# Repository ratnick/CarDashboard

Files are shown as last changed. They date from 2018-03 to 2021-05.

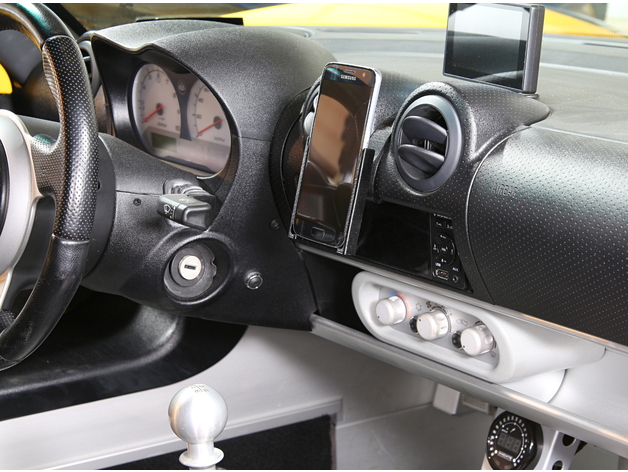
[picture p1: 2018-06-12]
3D print/Phone_mount_for_Lotus_Elise_Exige/images/8231e8743e852b0e2db3741e05d66e65_preview_featured.JPG

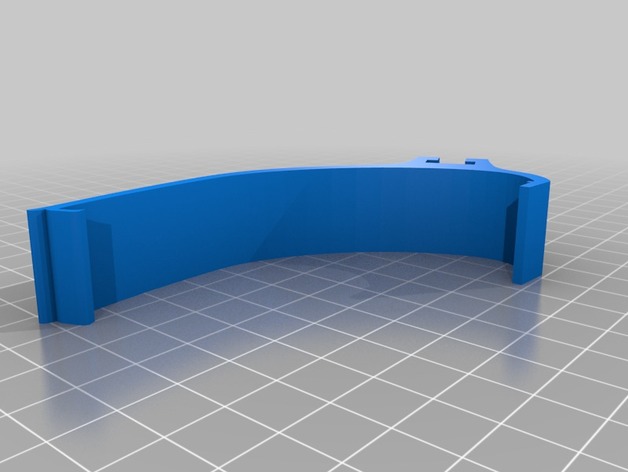
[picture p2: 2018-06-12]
3D print/Phone_mount_for_Lotus_Elise_Exige/images/de6a3d5b6df85b9659bbdc78314f558a_preview_featured.jpg

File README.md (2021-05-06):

# CarDashboard
General use: A dashboard built for car telemetry. 
UI targeted at trackday; i.e. clear no-nonsense visuals.
Content: tyre pressure, tyre temperature, outdoor temperature.
Built scalable to include more metrics.

Content:
Android app with interface to several sensors:
- tire temperature sensors mounted on top of tyre.
      + communicating via wifi/UDP.
      + Arduino based, battery powered, measuring with infrared heat sensor. 
- Tire pressure sensors:
      + communicating via BLE. 
      + VC601 type which seem to work best (https://www.aliexpress.com/item/32902607772.html?spm=a2g0s.9042311.0.0.27424c4dPwDtFs)
      + Chinese No Name which turned out to be unstable. But communication and decoding works (https://www.aliexpress.com/item/33041131063.html?spm=a2g0s.9042311.0.0.27424c4doWNTAi

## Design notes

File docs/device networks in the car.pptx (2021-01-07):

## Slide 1

WeMOS D1
Temp + humidity

NORMAL SETUP

”MX5 ratnick”
Router / AP

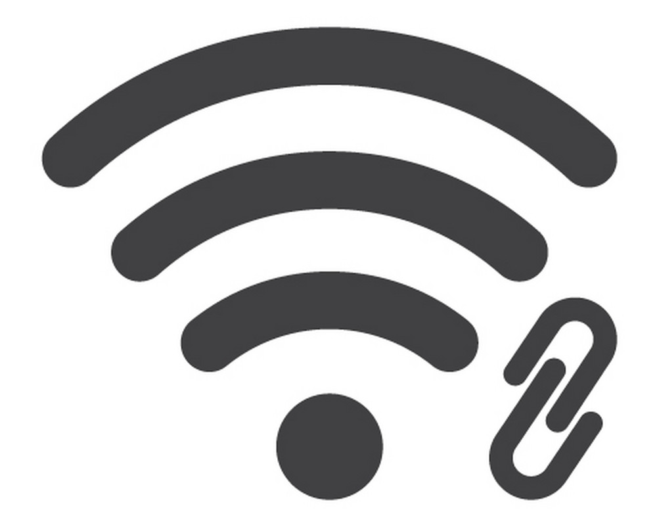
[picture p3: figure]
Wifi hotspot glyph icon web and mobile Royalty Free Vector

Android screen

CAR monitor

WeMOS temperature sensor

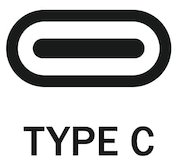
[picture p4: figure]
Usb C Icon Images, Stock Photos & Vectors | Shutterstock

Phone

Headset

Normal drive

12V

12V

TPMS monitor

TPMS sensors

RACE SETUP

”MX5 ratnick”
Router / AP

Android screen

CAR monitor

GoPro CAM

Phone

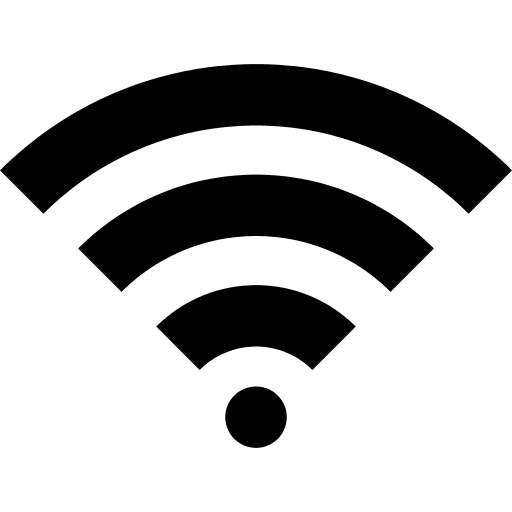
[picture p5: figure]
Wifi Symbol transparent PNG - StickPNG

Track
Addict

race

WeMOS temperature sensor

12V

12V

Race-GPS

TPMS monitor

TPMS sensors

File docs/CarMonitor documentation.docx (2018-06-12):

# Car monitor

Nikolaj Nøhr-Rasmussen

# Hardware

## Heat sensors

Wemos D1 Mini

MLX90614 heat sensor

BL-5C battery (http://www.cpkb.org/wiki/Nokia_BL-5C_battery_pinout)

## Display device

Android device (code made for 10.1”)

## Wiring

#### Heat sensor:

D1 Mini | MLX90614 heat sensor | BL-5C
3.3V | VIN | +
GND | GND | -
D1 | SCL
D2 | SDA
D0 wired to RST (to enable deep sleep)

#### Voltage sensor:

D1 Mini | | 12V battery
3.3V | | +
GND | | -
D1
D2
D0 wired to RST (to enable deep sleep)

# Functional Description

## Communication

### Principle

Host (Android tablet) and client (Arduino) communicates via UDP on wifi.

Both need to connect on Wifi hotspot.

Order of appearance is insignificant.

#### Basic initial handshake and sensor reading commands

Client | Host
send CMD_ASK_HOST_TO_JOIN_NETWORK
| Register client. Respond CMD_OK_TO_JOIN_NETWORK
Wait for next command from host (or timeout)
| Send CMD_READ_SENSOR_DATA to initiate sensor reading
Reply with sensor reading in CMD_SENSOR_DATA_REPLY

#### Reconnection if client has lost power or connection

Client | Host
send CMD_ASK_HOST_TO_JOIN_NETWORK
| (client already registered) Respond CMD_OK_TO_JOIN_NETWORK

#### Reconnection if host has lost power or connection

Client | Host
Repeat until reply from host: send CMD_ASK_HOST_TO_JOIN_NETWORK wait a few seconds go to deep sleep (if not reply received)
| Register client. Respond CMD_OK_TO_JOIN_NETWORK

#### Power saving when not in use: Set client in sleep mode

Client | Host
| Send CMD_READ_SENSOR_DATA to initiate sensor reading (always read sensor before going to deep sleep)
Reply with sensor reading in CMD_SENSOR_DATA_REPLY
| Send CMD_GOTO_DEEP_SLEEP (specifies deep sleep period)
Go to deep sleep When power up, it’s same sequence as a power down (i.e. a reconnection sequence)

All commands are in JSON format

CMD_ASK_HOST_TO_JOIN_NETWORK = 1;

CMD_OK_TO_JOIN_NETWORK = 2;

CMD_READ_SENSOR_DATA = 3;

CMD_SENSOR_DATA_REPLY = 4;

CMD_GOTO_DEEP_SLEEP = 5;

UDP_PORT = 1026;

## Deep sleep

Deep sleep occurs in the following situations:

- On reception of CMD_GOTO_DEEP_SLEEP from host
- If wifi connection cannot be established
- If host connection cannot be established

The duration of the deep sleep period is set through CMD_GOTO_DEEP_SLEEP. The default value (until this command is received for the first time) is deepSleepPeriod seconds (=30).

# UI

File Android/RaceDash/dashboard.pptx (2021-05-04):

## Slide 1

Battery

Oil temp

13.3V

70 ⁰C

14

16

34

20

Water temp

50 ⁰C

⁰C

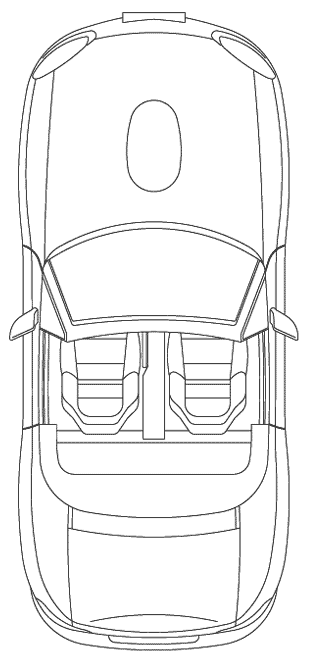
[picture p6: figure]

psi

RATNICK RACING

36

20

46

25

x

x

x

Last data

x

14:44:23

Wifi strength

-56 dB

Wifi SSID

MX-5

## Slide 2

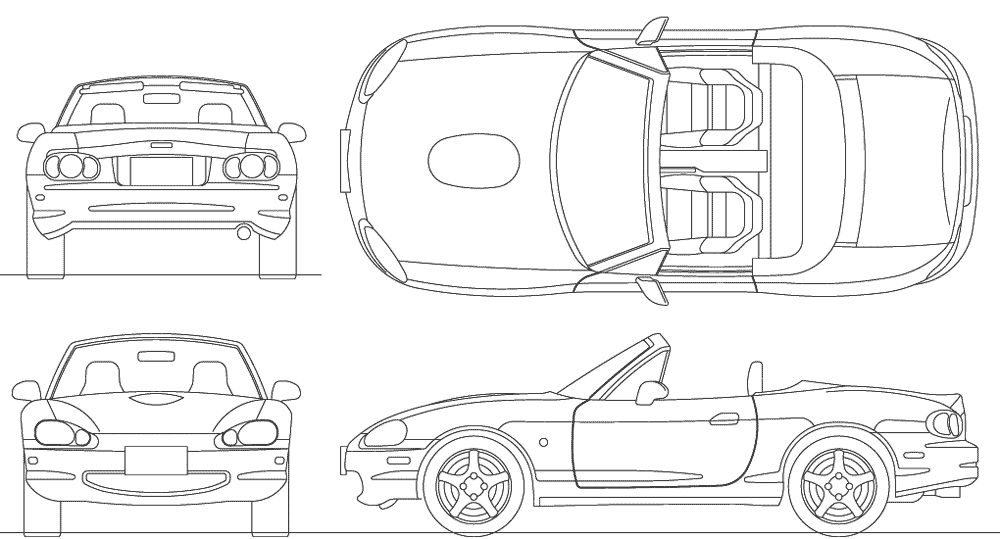
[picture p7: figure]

http://car-blueprints.narod.ru/images/mazda/mazda-mx-5.gif

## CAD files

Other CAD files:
3D print/Phone_mount_for_Lotus_Elise_Exige/files/Lotus_Phone_Mount.dwg
3D print/Phone_mount_for_Lotus_Elise_Exige/files/Galaxy_S7_holder_for_lotus_mount.skp
3D print/Phone_mount_for_Lotus_Elise_Exige/files/Lotus_Phone_Mount.skp
3D print/Phone_mount_for_Lotus_Elise_Exige/files/Sony_Z5C_holder_for_lotus_mount v2.skp
3D print/Phone_mount_for_Lotus_Elise_Exige/files/Tablet_holder_for_lotus_mount 1a.skp
3D print/Phone_mount_for_Lotus_Elise_Exige/files/Tablet_holder_for_lotus_mount 2.skp
3D print/Phone_mount_for_Lotus_Elise_Exige/files/Tablet_holder_for_lotus_mount.skp
3D print/WEMOS_D1_Mini_ENCLOSURE_with_BL-5C_NOKIA_battery___sensors_space/files/WeMOS D1 + BL5C box v2.f3d
3D print/WEMOS_D1_Mini_ENCLOSURE_with_BL-5C_NOKIA_battery___sensors_space/files/WeMOS D1 + sensor space + not up to date BL5C casing.f3d
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

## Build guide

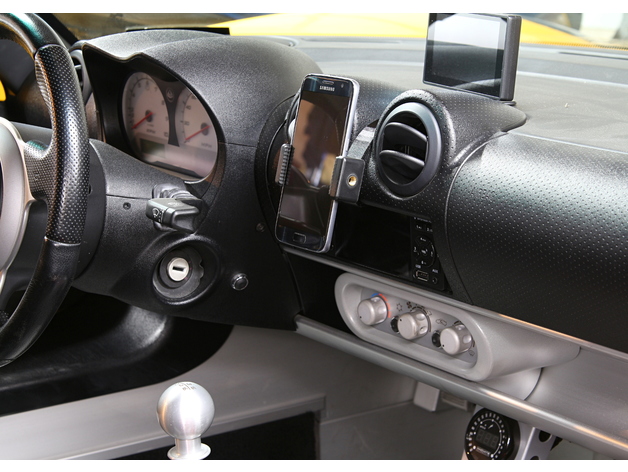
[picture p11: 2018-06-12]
3D print/Phone_mount_for_Lotus_Elise_Exige/images/54f9da398c1b73ae77cc9300c85436e2_preview_featured.JPG

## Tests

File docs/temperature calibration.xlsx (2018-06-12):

reel | målt | afstand | rum temp | 4 | 0.7
20 | 21 |  |  | 18.7 | 2.3
18 | 20 |  |  | 18 | 2
28 | 24 |  |  | 20.8 | 3.2
31 | 27 |  |  | 22.9 | 4.1
37 | 30 |  |  | 25 | 5
41 | 33 |  |  | 27.1 | 5.9
46 | 37 |  |  | 29.9 | 7.1
66 | 49 |  |  | 38.3 | 10.7
74 | 57 |  |  | 43.9 | 13.1
80 | 63 |  |  | 48.1 | 14.9
 |  |  |  |  | 68.3
4 | 0
60 | 80

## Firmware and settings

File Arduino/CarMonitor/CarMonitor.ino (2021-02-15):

/*
	Name:       CarMonitor.ino
	Author:     Nikolaj Nøhr-Rasmussen
*/

// Including the libraries below, allows to turn off Deep Search in libraries => faster compiling

#include "FirebaseLib.h"
#include <WifiLib.h>
#include <SysCall.h>
#include <sdios.h>
#include <SdFatConfig.h>
#include <SdFat.h>
#include <MinimumSerial.h>
#include <FreeStack.h>
#include <BlockDriver.h>
#include <SDFSFormatter.h>
#include <SDFS.h>
#include <SD.h>
#include <FirebaseJson.h>    // works with 2.2.8, but NOT 2.3.9. This will give random errors in communication with Firebase. I think it's becaise FirebaseJSON struct or class is changed
// end 

// OTA upload
#include <LEAmDNS_Priv.h>
#include <LEAmDNS_lwIPdefs.h>
#include <LEAmDNS.h>
#include <ESP8266mDNS_Legacy.h>
#include <ESP8266mDNS.h>
#include <ArduinoOTA.h>
// end


#include <FirebaseESP8266.h>
#include <ESP8266WiFi.h>
#include <WiFiUdp.h>
#include <WiFiServer.h>
#include <WiFiClient.h>

#include <SPI.h>
#include <FirebaseESP8266HTTPClient.h>

#include <SoftwareSerial.h>
#include <Wire.h>
#include <DHTesp.h>
#include <EEPROM.h>
#include <TimeLib.h>        // http://playground.arduino.cc/code/time - installed via library manager
#include <time.h>

// own libraries
#include "globals.h"
#include "OTALib.h"
#include <LogLib.h>
#include <ArduinoJson.h>



#define DEBUGLEVEL 4

// The Arduino device itself
Device device;

// For UDP
WiFiUDP UDP;

// Current sensorData
SensorData sensorData;

int i = 0;
time_t watchdogTimestamp;

uint32_t calculateCRC32(const uint8_t* data, size_t length) {

	uint32_t crc = 0xffffffff;
	while (length--) {
		uint8_t c = *data++;
		for (uint32_t i = 0x80; i > 0; i >>= 1) {
			bool bit = crc & 0x80000000;
			if (c & i) {
				bit = !bit;
			}
			crc <<= 1;
			if (bit) {
				crc ^= 0x04c11db7;
			}
		}
	}
	return crc;
}

void DoSampling() {
	StaticJsonBuffer<SENSORDATA_JSON_SIZE> jsonBuffer;
	JsonObject& jsonObject = jsonBuffer.createObject();

	readSensor();
	serializeJson_ReadSensorData(sensorData, jsonObject);
	jsonObject.prettyPrintTo(Serial);
	sendJsonViaUDP(jsonObject);
	// We expect to reach this point at least every WATCHDOG_TIMEOUT ms. If we don't re-initiate connection to host.
}

void GoToDeepSleep() {
	ESP.rtcUserMemoryRead(0, (uint32_t*)&rtcData, sizeof(rtcData));  // store value in deep-sleep persistent memory 
	deepSleepPeriod = rtcData.deepSleepPeriod;

	if (deepSleepPeriod > 0) {
		Serial.println("Going to deep sleep");
		watchdogTimestamp = now() + deepSleepPeriod;
		Serial.print("GoToDeepSleep(): deepSleepPeriod = ");
		Serial.println(deepSleepPeriod);
//		ESP.deepSleep(deepSleepPeriod * 1000000);
	}	else {
		Serial.println("Deep sleep request NOT met. Value is zero");
	}
}

void ProcessCommand(int CmdID) {
	StaticJsonBuffer<SENSORDATA_JSON_SIZE> jsonBuffer;
	JsonObject& jsonObject = jsonBuffer.createObject();

	switch (CmdID) {
		case CMD_GOTO_DEEP_SLEEP:
			Serial.print("\nCMD_GOTO_DEEP_SLEEP");
			GoToDeepSleep();
			break;
		case CMD_READ_SENSOR_DATA:
			Serial.print("\nCMD_READ_SENSOR_DATA");
			readSensor();
			serializeJson_ReadSensorData(sensorData, jsonObject);
			jsonObject.prettyPrintTo(Serial);
			sendJsonViaUDP(jsonObject);
			// We expect to reach this point at least every WATCHDOG_TIMEOUT ms. If we don't re-initiate connection to host.
			watchdogTimestamp = now() + WATCHDOG_TIMEOUT;
			Serial.println(": EXECUTED");
			break;
	}
}

void initDeviceConfig() {
	device.boardType = WeMos;            // BoardType enumeration: NodeMCU, WeMos, SparkfunThing, Other (defaults to Other). This determines pin number of the onboard LED for wifi and publish status. Other means no LED status 
	device.deepSleepSeconds = 0;         // if greater than zero with call ESP8266 deep sleep (default is 0 disabled). GPIO16 needs to be tied to RST to wake from deepSleep. Causes a reset, execution restarts from beginning of sketch

	// read static data and ensure they are valid theough CRC check
	ESP.rtcUserMemoryRead(0, (uint32_t*)&rtcData, sizeof(rtcData));

	// check validity of data (https://github.com/esp8266/Arduino/blob/master/libraries/esp8266/examples/RTCUserMemory/RTCUserMemory.ino)
	uint32_t crcOfData = calculateCRC32((uint8_t*)&rtcData.deepSleepPeriod, sizeof(rtcData.deepSleepPeriod));
	Serial.print("CRC32 of data: ");
	Serial.println(crcOfData, HEX);
	Serial.print("CRC32 read from RTC: ");
	Serial.println(rtcData.crc32, HEX);
	if (crcOfData != rtcData.crc32) {
		Serial.println("CRC32 in RTC memory doesn't match CRC32 of data. Data is probably invalid! Re-initialize");
		rtcData.deepSleepPeriod = DS_INIT_VALUE;
		rtcData.crc32 = crcOfData;
		ESP.rtcUserMemoryWrite(0, (uint32_t*)&rtcData, sizeof(rtcData));
	}
	else {
		Serial.println("CRC32 check ok, data is probably valid.");
	}
}

void ConnectToWifi() {
	int wifiIndex = initWifi(&device.wifi);
	delay(250);
	if (wifiIndex == -1 || WiFi.status() != WL_CONNECTED) {
		LogLine(0, __FUNCTION__, "Could not connect to wifi. ");
	}
	else if (wifiIndex == 100 || wifiIndex == 200) {
		// Connected. Do nothing.
	}
	else {
		PrintIPAddress();
	}
}

void setup() {

	String wifiname;
	String wifipwd;

	Serial.begin(115200);
	Serial.println("CarMonitor START");
	InitDebugLevel(DEBUGLEVEL);

	initFlashLED();
	LED_Flashes(5, 25);
	delay(100);
	initDeviceConfig();
	setupSensor();
	ConnectToWifi();
	PrintIPAddress();
	SetupOTA();

}


void loop() {

	int cmdID;

	ArduinoOTA.handle();
	// for test
	ProcessCommand(CMD_READ_SENSOR_DATA);

	if (WiFi.status() == WL_CONNECTED) {
		if (udpConnected && (now() < watchdogTimestamp) ) {
			cmdID = ReadCmdFromUDP();
			ProcessCommand(cmdID);
			delay(200);
		} else {
			if (initUDP()) {
				watchdogTimestamp = now() + WATCHDOG_TIMEOUT;
			} else {
				Serial.println("InitUDP: Could not connect to host: ");
				delay(2000);
				GoToDeepSleep();
			}
		}
	}
	else {
		initWifi(&device.wifi);
		delay(250);
		if (WiFi.status() != WL_CONNECTED) {
			Serial.print("\nCould not connect to wifi: ");
			GoToDeepSleep();
		}
	}
}

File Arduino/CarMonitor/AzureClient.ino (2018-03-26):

#include <ESP8266WiFi.h>
#include <Wire.h>
#include <TimeLib.h>        // http://playground.arduino.cc/code/time - installed via library manager
#include "globals.h"        // global structures and enums used by the applocation
#include <time.h>
#include "Constants.h"

// Workflow
#define DOWNLOAD_PICTURE_FROM_WEB false
#define TAKE_AND_UPLOAD_PICTURE_TO_BLOB true
#define CALL_BARCODERECOGNITION_WEBJOB true

// The Arduino device itself
DeviceConfig wifiDevice;

// Wifi and network globals
#define AT_HOME false
#define XPERIAHOTSPOT true

const char timeServer[] = "0.dk.pool.ntp.org"; // Danish NTP Server 
WiFiClient wifiClient;

// Image storage globals
MessageData msgData;

// Enable below if you want to read the whole image from the camera into an internal buffer. This limits the image size.
// Disable if you want to read directly from camera to http request without internal buffering. Works for all image sizes.
//#define USE_IMAGE_BUFFER 
#ifdef USE_IMAGE_BUFFER
	#define MAX_IMAGE_SIZE 10000 // if compile problem "Error linking for board WeMos D1 R2 & mini" reduce this number to reduce memory footprint
	imageBufferSourceEnum imageBufferSource = InternalImageBuffer;
#else
	#define MAX_IMAGE_SIZE 1 
	imageBufferSourceEnum imageBufferSource = DirectFromCamera;
#endif
byte imageBuffer[MAX_IMAGE_SIZE]; //nnr char imageBuffer[10000];

// Azure Cloud globals
CloudConfig cloud;


void initDeviceConfig() {
	wifiDevice.boardType = Other;            // BoardType enumeration: NodeMCU, WeMos, SparkfunThing, Other (defaults to Other). This determines pin number of the onboard LED for wifi and publish status. Other means no LED status 
	wifiDevice.deepSleepSeconds = 0;         // if greater than zero with call ESP8266 deep sleep (default is 0 disabled). GPIO16 needs to be tied to RST to wake from deepSleep. Causes a reset, execution restarts from beginning of sketch
}

void setup() {

	String wifiname;
	String wifipwd;

	Serial.begin(115200);
	Serial.println("AzureClient START");

	initFlashLED();
	LED_Flashes(5, 25);
	initArduCAM();
	delay(100);
	initWifiCredentials(wifiname, wifipwd);
	initDeviceConfig();
	azureCloudConfig(wifiname, wifipwd);
	initWifi();
	//initialiseAzure(); // https://msdn.microsoft.com/en-us/library/azure/dn790664.aspx  
}

void loop() {
	int published = false;
	int dataSize = 0;	
	boolean success = false;
	long bytesRead = 0;

	getCurrentTime();

	if (TAKE_AND_UPLOAD_PICTURE_TO_BLOB) {
		if (DOWNLOAD_PICTURE_FROM_WEB) {
			// This snippet gets image from http server somewhere (for testing)
			//success = readReplyFromServer(imageBuffer, msgData.blobSize);
			//while (!getImageData()) {
				// keep trying
				//Serial.println("ERROR: Problem fetching test image. Terminating");
				//delay(2000);
			//} 
		}
		else {
			LED_ON();
			takePicture(msgData.blobSize);  // note that this number indicates the size of the CROPPED image
			LED_OFF();
		}
		if (imageBufferSource == InternalImageBuffer) {
			LED_ON();
			readPicFromCamToImageBuffer(imageBuffer, msgData.blobSize);
			LED_OFF();
			dumpImageData(imageBuffer, msgData.blobSize);
		}
		else {
			// do nothing. The pic will be read directly from the camera from transmitDataOnWifi called by UploadToBlobOnAzure
		}
	}
	else {
		Serial.println("NO PHOTO TAKEN (enable compile flag to do this)");
	}
	msgData.blobName = FIXED_BLOB_NAME; 
	msgData.fullBlobName = "/" + String(cloud.storageContainerName) + "/" + String(cloud.deviceId) + "/" + String(msgData.blobName); // code39ex1.jpg";// " / input / " + String(cloud.deviceId) + " / input / " + String(msgData.blobName);

	if (WiFi.status() == WL_CONNECTED) {
		//Serial.println("WiFi.status() == WL_CONNECTED");

		if (TAKE_AND_UPLOAD_PICTURE_TO_BLOB) {
			if (UploadToBlobOnAzure(imageBufferSource, imageBuffer)) {
				Serial.println("Published Blob to Azure.");
			}
			else {
				Serial.println("ERROR: Could not publish Blob to Azure.");
			}
			delay(5000); // Cloud needs a little time to settle
		}

		if (CALL_BARCODERECOGNITION_WEBJOB) {
			if (SendDeviceToCloudHttpFunctionRequest(imageBufferSource, imageBuffer)) {
				//Serial.println("Sent HTTPPOST Trigger request to Azure: SUCCESS");
			}
			else {
				Serial.println("Sent HTTPPOST Trigger request to Azure: ERROR or no recognition");
			}
		}

/*		if (wifiDevice.deepSleepSeconds > 0) {
		  ESP.deepSleep(1000000 * wifiDevice.deepSleepSeconds, WAKE_RF_DEFAULT); // GPIO16 needs to be tied to RST to wake from deepSleep. Execute restarts from beginning of sketch
		}
		else {
		  delay(cloud.publishRateInSeconds * 1000);  // limit publishing rate
		}
*/	}
	else {
		initWifi();
		delay(250);
	}
	closeCamera();
	Serial.println("Stopping.");

	LED_OFF();    // turn the LED off by making the voltage LOW

	while (true) { delay(10000); Serial.print("#"); } //endless loop. We're done

}

void dumpImageData(byte *buf, long nbrOfBytes) {

	long length = 0;

	Serial.printf("\dumpImageData: %d bytes \n", length);

	while (length++ < nbrOfBytes)
	{
		if (length % 50 == 0) {
			Serial.print(length-1); Serial.print("=");; Serial.print((int)buf[length-1]); Serial.print(" ");
		}
	}

}


void dumpBinaryData(byte *buf, long nbrOfBytes) {

	long i = 0;
	Serial.printf("\dumpBinaryData: %d bytes \n", nbrOfBytes);

	while (i < nbrOfBytes)
	{
		Serial.printf("%d=%x ", i, (char)buf[i]);
		i++;
	}
}

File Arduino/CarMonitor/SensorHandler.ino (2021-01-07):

#include <DHTesp.h>
#include <Wire.h>
#include <Adafruit_MLX90614.h>

// http://www.arduinoprojects.net/temperature-projects/mlx90614-infrared-thermometer.php#codesyntax_1

Adafruit_MLX90614 mlx = Adafruit_MLX90614();

// DHT
DHTesp dht;


void setupSensor() {
	Serial.print("\nSensor name = ");
	Serial.println(sensorData.deviceID);

	switch (device.sensorType) {
		case HeatSensor:
			setupHeatSensor();
			break;
		case VoltageSensor:
			; //do nothing
			break;
		case HumAndTempDHTSensor:
			setupHumAndTempDHTSensor(); 
			break;
	}
	ReadI2CAddresses();
}

void setupHeatSensor()
{
	mlx.begin();
}

void setupHumAndTempDHTSensor()
{
	dht.setup(DIGITAL_IN_PIN, DHTesp::DHT11); // Connect DHT sensor to GPIO DIGITAL_IN_PIN
}

void readSensor() {
	switch (device.sensorType) {
		case HeatSensor:
			readHeatSensor();
			break;
		case VoltageSensor:
			readVoltageSensor();
			break;
		case HumAndTempDHTSensor:
			readHumAndTempDHTSensor();
			break;
	}
}

void readHeatSensor()
{
	sensorData.temperature = mlx.readObjectTempC();
	sensorData.ambTemperature = mlx.readAmbientTempC();

	Serial.print("\nreadHeatSensor: temp = ");
	Serial.print(sensorData.temperature);
	Serial.print(", amb.temp = ");
	Serial.println(sensorData.ambTemperature);

}


void readVoltageSensor()
{
	sensorData.temperature = 12.0*analogRead(A0)/600;

	Serial.print("\readVoltageSensor: Voltage = ");
	Serial.println(sensorData.voltage);
}

void readHumAndTempDHTSensor()
{
	delay(dht.getMinimumSamplingPeriod());

	float humidity = dht.getHumidity();
	float temperature = dht.getTemperature();

	Serial.print(dht.getStatusString());
	Serial.print("\thum=");
	Serial.print(humidity, 1);
	Serial.print("\t\t temp=");
	Serial.print(temperature, 1);
	sensorData.humidity = humidity;
	sensorData.temperature = temperature;
}

void ReadI2CAddresses() {

	Serial.println("Scanning for attached I2C devices ...");
	byte count = 0;

	Wire.begin();
	for (byte i = 8; i < 120; i++)
	{
		Wire.beginTransmission(i);
		if (Wire.endTransmission() == 0)
		{
			Serial.print("Found address: ");
			Serial.print(i, DEC);
			Serial.print(" (0x");
			Serial.print(i, HEX);
			Serial.println(")");
			count++;
			delay(1);  // maybe unneeded?
		} 
	} 
	Serial.print("Found ");
	Serial.print(count, DEC);
	Serial.println(" device(s).");
} 

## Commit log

2018-03-26 Initial working version: - 4 pre-registered sensors (one for temperature on each wheel) - Prepared for unknown sensors (but not tested) - UDP command handshake + device registration - deep sleep supp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
    [v8 D1 + BL5C box v2.f3d]
2018-03-29 Arduino: Introduced Deep Sleep for arduino. Android: Baseline before introducing one thread per device in Android. 3D: a layout that works.
    [WeMOS D1 + BL5C box v2.f3d, WeMOS D1 + sensor space + not up to date BL5C casing.f3d, WeMOS D1 + sensor space.f3d]
2018-06-12 Enhanced standby. Transfer function for temperature readings. I2C address read.
    [Galaxy_S7_holder_for_lotus_mount.skp, Log-20170917-095200 Knutstorp - 1.18.877.csv, Lotus_Phone_Mount.dwg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]
2020-03-15 - Updated UI to better fit any screen - 5 unassigned engine parameters. Assigned through XML from devices
2020-12-30 Included OTA uploads option. Changed min-max values for temperature
2021-05-04 Preliminary updates to reflect new BLE sensor
    Preliminary updates to reflect new BLE sensor
    [analysis of bytes from sensor.xlsx]
